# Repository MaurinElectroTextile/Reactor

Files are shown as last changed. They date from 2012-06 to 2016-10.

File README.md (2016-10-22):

# Tricot Reactor

### Musicals clothing made out of stretch knitted fabric sensor

S’habiller avec des vêtements technologiques c’est stylé! c’est un jeu comme le cosplay, une manière d’incarner son temps dans la mixité des influences passées, présentes et futures. Les vêtements interactifs et musicaux que nous imaginons pourraient s’inscrire dans une démarche artistique et performative mais nous avons décidé de nous adresser à un public plus large. Augmenté d'un "parfum sonore" le tricot Reacor est une sorte de vetement instrument. Rendu réactif grâce à l’intégration d’une petite carte électronique, le tricot Reactor permet d’imaginer une multitude de modèles de vêtements instruments. Tricoté à la main à partir de fils de laine et de fils conducteurs, la maille permet ainsi de capter l’élongation, la tension du tissu ainsi que les plis et contacts de la matière pour déclencher ou contrôler des sons. Une attention particulière est portée à l’intégration de l'électronique qui disparaît totalement au profit d’une esthétique simple. Intergénérationnel, ce projet est aussi un prétexte pour organiser des ateliers avec des grand mères branchées qui pourront remettre leur tricot au goût du jour.

Tricot-Reactor (https://www.flickr.com/photos/maurin/18238759816/in/dateposted-public/ "Click to watch the video!")

## Scénarios

### Suivi de partition
A chaque fois que l’on bouge, presse ou plie le tricot, on "avance" d’une note dans une mélodie. Le rythme de cette mélodie correspond ainsi au rythme du mouvement de celui ou celle qui porte le vêtement et la composition fonctionne en boucle.

### Aléatoire contrôlé
Nous choisissons ici de distinguer plusieurs typologies de mouvement calme, en marche, excité, etc. Chacune de ces typologies est déterminée par la fréquence des mouvements captés. Plus on s’excite, plus les sons déclenchés sont aigus et distordus, à l’inverse, plus on est calme et plus les sons se réduisent à une sonorité simple.

### Le son extensible
Le stress exercé sur le tricot est générateur d’un son qui varie en relation directe avec l’étirement de la matière, plus le tricot est tendu plus le son est aigu. L’onde sonore est générée par synthèse. Une carte électronique dédiée permet de programmer plusieurs types de sons qui se rapprochent des sons 8-bit. Cette orientation fera l’objet d’une mise au point ultérieure car vous avons souhaité privilégier dans un premier temps une solution qui utilise des samples.

### Le son polyphonique
Dans ce dernier scénario le son sera généré par un téléphone portable assisté d’un mini système son. Ce téléphone sera aussi équipé d’une application musicale contrôlée par le vêtement. Pour réaliser un premier prototype nous avons choisi de travailler avec le système Android et donc d’aborder le développement d’une application en Java...

## Electronic
Pull on the knit cause resistor drop down. A voltage divider circuit is used to convert resistor variation into voltage value (Vs). This is done by adding a single 10K resistor (R2). To reduce power consumption of the voltage divider, the circuit is supplied (VCC) with a digital IO pin that allow on/off switching.The sketch is also implementing sleep mode.



The first prototype was using an ATTiny85 and a SOMO-4D (embedded audio-sound module) to build a small stand alone audio player. [This tutoriel explain how to program ATTiny with Arduino](http://hlt.media.mit.edu/?p=1229)

## TODO
- Translate the text in english
- Replace the SOMO with the [Teensy 3.2](https://www.pjrc.com/teensy/teensy31.html)
- Add a small amplifier

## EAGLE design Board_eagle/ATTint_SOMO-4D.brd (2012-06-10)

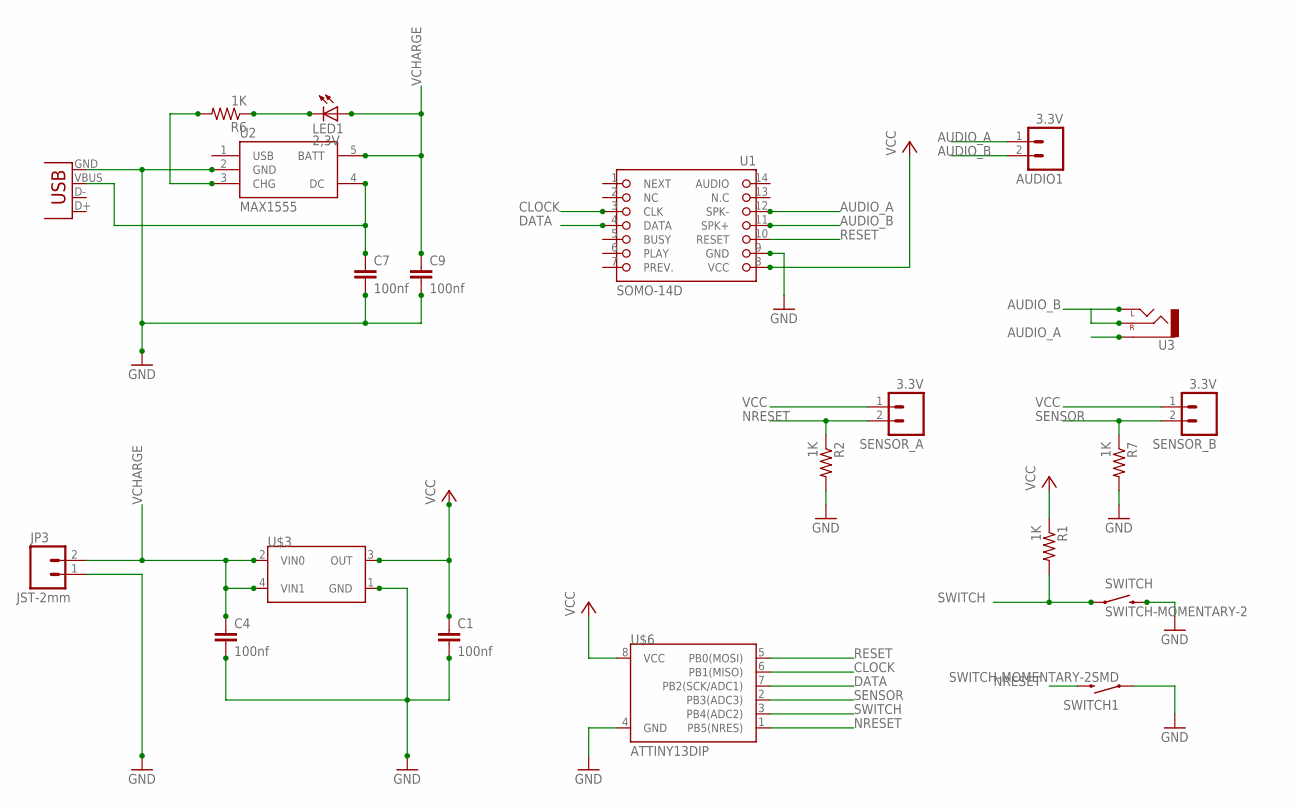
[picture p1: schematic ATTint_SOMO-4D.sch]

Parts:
AUDIO1: 3.3V; 1X02_LOCK_LONGPADS
C1, C4, C7, C9: 100nf; 0805
JP3: JST-2mm; JST-2-SMD
LED1: 2,3V; CHIP-LED0805
R1, R2, R6, R7: 1K; 0805
SENSOR_A: 3.3V; 1X02_LOCK_LONGPADS
SENSOR_B: 3.3V; 1X02_LOCK_LONGPADS
SWITCH: SWITCH-MOMENTARY-2; TACTILE_SWITCH_TALL
SWITCH1: SWITCH-MOMENTARY-2SMD; TACTILE_SWITCH_SMD
U1: SOMO-14D
U2: MAX1555; SOT23-5
U3: AUDIO-JACKSMD2; AUDIO-JACK-3.5MM-SMD
U$3: MCP1703; SOT-89
U$6: ATTINY13DIP; DIP08
X3: USB-SMD-NS; USB-MINIB-NOSTOP

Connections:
AUDIO_A: AUDIO1.1, U1.12 (SPK-), U3.SLEEVE
AUDIO_B: AUDIO1.2, U1.11 (SPK+), U3.RING (RIGHT), U3.TIP (LEFT)
CLOCK: U1.3 (CLK), U$6.6 (PB1(MISO))
DATA: U1.4 (DATA), U$6.7 (PB2(SCK/ADC1))
GND: C1.2, C4.2, C7.2, C9.2, JP3.1, R2.2, R7.2, SWITCH.B2 (2), SWITCH1.1, U1.9 (GND), U2.2 (GND), U$3.1 (GND), U$6.4 (GND), X3.GND
unnamed: C7.1, U2.4 (DC), X3.VBUS
unnamed: R6.2, U2.3 (CHG)
unnamed: LED1.C, R6.1
NRESET: R2.1, SENSOR_A.2, SWITCH1.3 (2), U$6.1 (PB5(NRES))
RESET: U1.10 (RESET), U$6.5 (PB0(MOSI))
SENSOR: R7.1, SENSOR_B.2, U$6.2 (PB3(ADC3))
SWITCH: R1.2, SWITCH.A2 (1), U$6.3 (PB4(ADC2))
VCC: C1.1, R1.1, SENSOR_A.1, SENSOR_B.1, U1.8 (VCC), U$3.3 (OUT), U$6.8 (VCC)
VCHARGE: C4.1, C9.1, JP3.2, LED1.A, U2.5 (BATT), U$3.2 (VIN0), U$3.4 (VIN1)

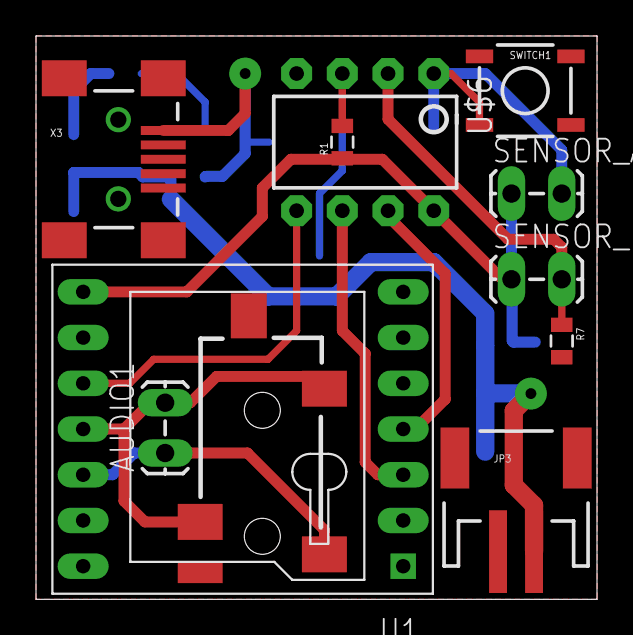
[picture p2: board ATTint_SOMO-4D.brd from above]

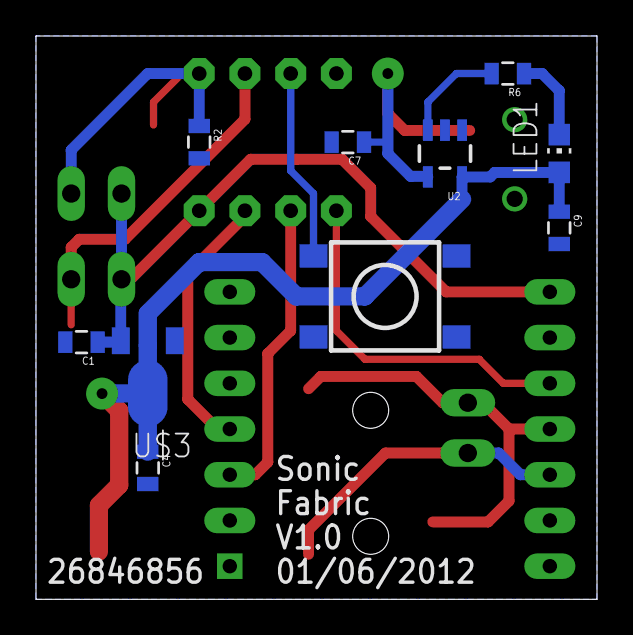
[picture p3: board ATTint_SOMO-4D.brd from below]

Board: 2 copper layers, 31.2 x 31.3 mm, 21 parts (10 on the bottom side), 14 nets.

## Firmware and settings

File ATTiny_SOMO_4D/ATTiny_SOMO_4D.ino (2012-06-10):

// This project is combining ATTiny85 and SOMO-4D module
// the electronic board is made for stand alone audio player controlled by a knitted fabric sensor
// this sketch implement sleep mode to reduce power consumption
////////////////////
#include <avr/sleep.h>
#include <avr/wdt.h>         // Watchdog timer handling

unsigned int volume[] = {
  0xfff0, 0xfff1, 0xfff2, 0xfff3, 0xfff4, 0xfff5, 0xfff6, 0xfff7
};

const int clockPin = 0;           // SOMO-4D clock pin
const int dataPin = 1;            // SOMO-4D data pin
const int resetPin = 2;           // ATTiny analog 1 to SOMO-4D reset pin
const int volumePin = 4;          // ATTiny analog 2 as input to trigger SOMO-4D volume
const int sensorPin = 3;          // ATTiny analog 3 to sens potentiometer scarf
const int DEBOUNCETIME = 100;      // debounce to avoid double playing instructions
const int THRESHOLD_SENS = 35;    // threshold for analog input sensing
const int INACTIVETIME = 500;     // time before sleeping mode
const int THRESHOLD_SWITCH = 100; //

unsigned long curentMillis = 0;
unsigned long lastPlayingTime = 0;
unsigned long curentInactiveTime = 0;

unsigned int rowSensorVal = 0;
unsigned int lastRowSensorVal = 0;
int derivee = 0;
boolean toggle = false;
boolean toggelsomoLowPower = true;


boolean volumeSwitch = 0;
boolean toggelSwitch = true;
unsigned int curentVolume = 7;

unsigned int pos = 0;

/////////////////////// initialisation
void setup(){

  pinMode(clockPin, OUTPUT);  // set pin to output for clock
  pinMode(dataPin, OUTPUT);   // set pin to output for data
  pinMode(resetPin, OUTPUT);  // set pin to output for reset

  // ajouter une resistance pullUp sur la carte pour l'interrupteur de vollume
  pinMode(volumePin, INPUT);      // set pin to input for volume control
  digitalWrite(volumePin, HIGH);  // enable internal pull-up resistor

  digitalWrite(clockPin, HIGH);
  digitalWrite(dataPin, LOW);

  //////////////////////////////////////// initialize watchdog timer
  sendData(volume[curentVolume]);          // set SOMO-4D volume
  WDT_Init();
  somoReset();
}

/////////////////////// boucle principale
void loop(){

  curentMillis = millis();

  if((curentMillis - lastPlayingTime) >= DEBOUNCETIME){

    if((curentMillis - lastPlayingTime) >= INACTIVETIME && derivee < THRESHOLD_SENS){
      
      if(toggelsomoLowPower) somoLowPower();
      toggelsomoLowPower = false;

      enable_wdt();
      sleepNow();
      disable_wdt();
    }

    rowSensorVal = analogRead(sensorPin);
    derivee = rowSensorVal - lastRowSensorVal;
    lastRowSensorVal = rowSensorVal;

    if(toggle == true && derivee >= THRESHOLD_SENS){
      lastPlayingTime = curentMillis;
      toggelsomoLowPower = true;
      
      toggle = false;                  // toggel only one time
      // sendData(sound[random(7)]);
      sendData(int(pos++ % 36));
    }
    if(toggle == false && derivee < THRESHOLD_SENS){
      toggle = true;
    }
  }
}

///////////////////////////////////////// fonctions

/////////////////////// Watchdog Interrupt Service Routine
// EMPTY_INTERRUPT(WDT_vect);
ISR(WDT_vect){  // go back to the main loop when we get an interrupt from the watchdog timer
  toggle = true;
}

/////////////////////// Init ATTiny WDT
void WDT_Init(void){
  WDTCR = 0x00;                   // clear WDTCR register
}

///////////////////////  Put ATTiny to sleep
void sleepNow(){
  set_sleep_mode(SLEEP_MODE_PWR_DOWN);  // Enter power down mode
  sleep_mode();                         // put to sleep
}

/////////////////////// Set ATTiny WDT ON
void enable_wdt(void){
  cli();
  wdt_reset();
  WDTCR |= (1 << WDCE) | (1 << WDE);                                 // enable WDT 4 cycle timer operation bit 
  // WDTCR |= (1 << WDE) | (1 << WDIE) | (1 << WDP2);                // 0.25s timeout, interrupt mode
  WDTCR |= (1 << WDE) | (1 << WDIE) | (1 << WDP2) | (1 << WDP1);     // 1.0s timeout, interrupt mode
  // WDTCR |= (1 << WDE) | (1 << WDIE) | (1 << WDP3);                // 4.0s timeout, interrupt mode
  sei();
}

/////////////////////// Set ATTiny WDT OFF
void disable_wdt(void){
  cli();
  MCUSR = 0;                              // Clear WDRF in MCUSR
  WDTCR |= (1 << WDCE) | (1 << WDE);      // enable WDT 4 cycle timer operation bit 
  WDTCR = 0x00;                           // Turn off WDT 
  sei();
}

/////////////////////////////// send data to SOMO module
void sendData(int thisSong){
  int theSong = thisSong;
  int clockCounter = 0;
  int clockCycle = 15;

  // digitalWrite(clockPin, HIGH); // Hold (idle) for 300msec to prepare data start
  digitalWrite(clockPin, LOW);  // Hold for 2msec to signal data start
  //delay(2);                   // 2msec delay
  delayMicroseconds(260);       //

  while(clockCounter <= clockCycle){
    digitalWrite(clockPin, LOW);
    if(theSong & 0x8000){
      digitalWrite(dataPin, HIGH);
    } 
    else {
      digitalWrite(dataPin, LOW);
    }
    theSong = theSong << 1;
    delayMicroseconds(25); // Clock cycle period is 200 uSec - LOW
    digitalWrite(clockPin, HIGH);
    clockCounter++;
    delayMicroseconds(25); // Clock cycle period is 200 uSec - HIGH
  }
  digitalWrite(dataPin, LOW);
  digitalWrite(clockPin, HIGH); // Place clock high to signal end of data
}

/////////////////////// Reset SOMO-4D
void somoReset(){
  digitalWrite(resetPin, LOW);
  delay(10);
  digitalWrite(resetPin, HIGH);
}

/////////////////////// SOMO-4D low power mode
// Stops playing the current audio file and puts the module in the ow power idle mode.
void somoLowPower(){
  sendData(0xFFFF);
  // digitalWrite(resetPin, LOW);
  // delay(130);
  // digitalWrite(resetPin, HIGH);
}

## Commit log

2012-05-28 Arduino ATTiny
    sleep mode implemented
2012-05-28 Sub directory
    Added sub directory
    [ATTint_SOMO-4D.brd, ATTint_SOMO-4D.sch]
2012-05-31 README
    add pin mapping for SOMO-4D and ATTiny85
2012-06-04 Code cleaning
    [ATTint_SOMO-4D.brd, ATTint_SOMO-4D.sch]
2012-06-10 optimised sleeping consumption
    [ATTint_SOMO-4D.brd, ATTint_SOMO-4D.sch]

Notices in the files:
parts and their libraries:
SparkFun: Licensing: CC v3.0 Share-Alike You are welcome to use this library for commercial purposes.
